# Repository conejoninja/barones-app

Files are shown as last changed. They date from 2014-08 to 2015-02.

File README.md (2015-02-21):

Breathalyzer on your smartphone
===

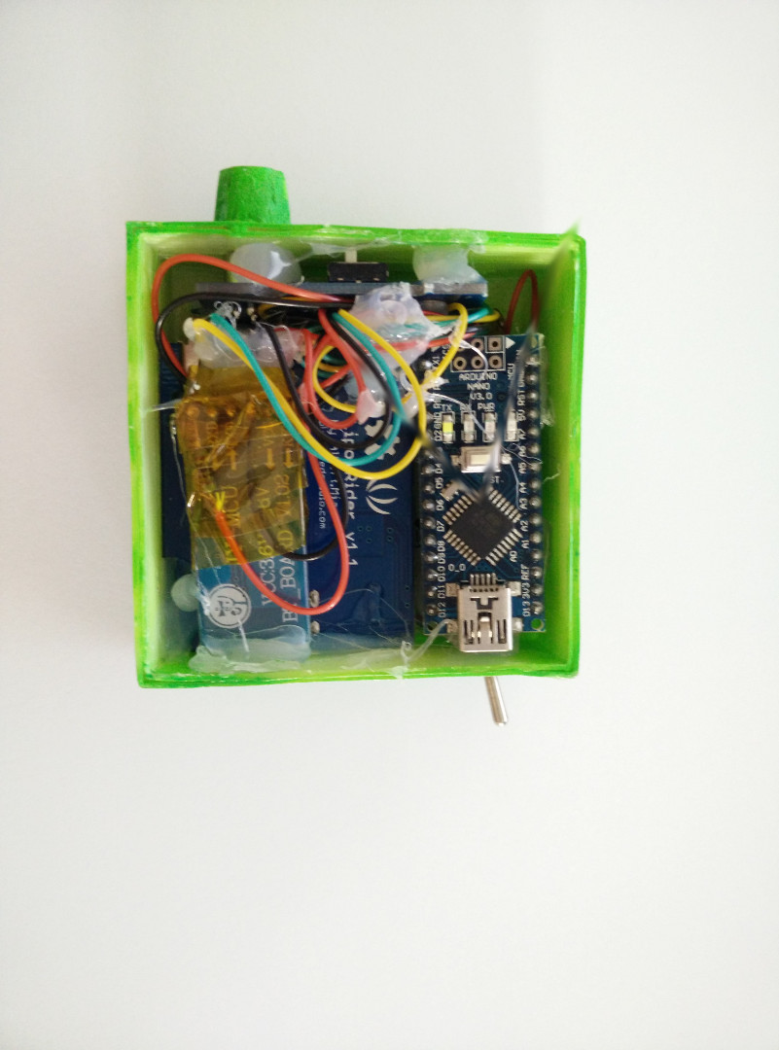
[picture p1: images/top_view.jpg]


Connect a breathalyzer to your smartphone and take pictures of your drunk friends with their highscores.
This project was around two years in the making, I started doing it in Java (the Android part) but got frustrated and left the project sitting in a box all this time. For the smartphone app I'm using phonegap/cordova, so it should work on iOS or windows phone, or at least, it should be easy to be ported. 

The idea isn't new, but all similar projects I found, didn't share the smartphone app's code, I do. It isn't the nicest app you could find, but it works.

I tried to recover all the information I wrote done when I first build this, I got most important information but some details and pictures are missing.

Bill of materials
===
* 1 Arduino nano 9-10€ , there a lot of different models and places to buy it
* 1 Grove-Alcohol sensor (seeedstudio) 5.90€ (7.90$) - http://www.seeedstudio.com/depot/Grove-Alcohol-Sensor-p-764.html
* 1 Li-po rider (seeedstudio) 7.08€ (9.50$) - http://www.seeedstudio.com/depot/Lipo-Rider-p-710.html
* 1 DSO Nano v2 replacement battery (seeedstudio) 4.10€ (5.50$) - http://www.seeedstudio.com/depot/DSO-Nano-v2-replacement-battery-p-738.html
* 1 Bluetooth module 4.80€ (6.43$) - http://www.dx.com/p/jy-mcu-arduino-bluetooth-wireless-serial-port-module-104299 (I think I bought it from ebay, and bought a pair, but is similar to this if not the same) 
* 1 Shipping from seeedstudio 2.56€ (3.44$)
* 1 3D printed case and paint 5€ (no idea, as I printed it mayself, but a small plastic case shouldn't cost much more)
* 1 switch, 2 leds, glue,.. less than 2-3€

**Aproximate cost: 40-45€**

Alcohol sensor
===

Schematics and code was taken from here : http://www.seeedstudio.com/wiki/index.php?title=Twig_-_Alcohol_Sensor
It uses the MQ303A.

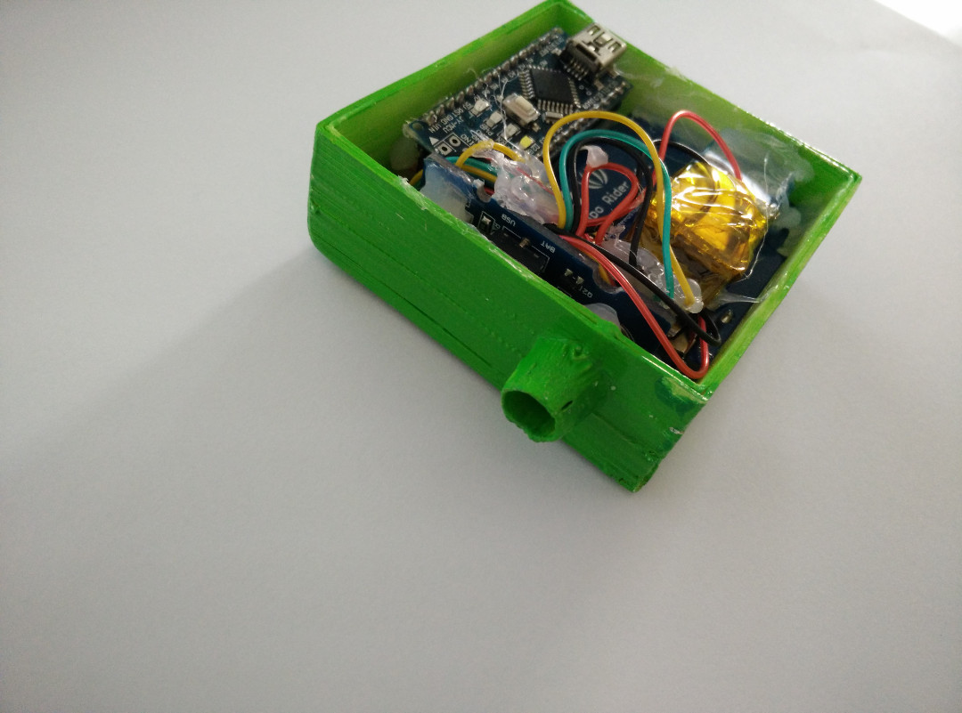
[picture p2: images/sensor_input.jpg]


Features
---

* Input Voltage: 5V
* Working Current: 120mA
* Detectable Concentration: 20-1000ppm
* Grove Compatible connector
* Highly sensitive to alcohol.
* Fast response and resumes quickly after alcohol exposure.
* Long life.
* Compact form factor.

Notes
---
To get better measurement, sensor needs to be power on for several hours before usage. Since this is a "for-fun" app, there's no need to wait long time, and after a few minutes (20-30min) readings are more or less stable. It could last several hours with one full charge of battery. 

Bluetooth module
===
I use the *JY-MCU* module, very famous and cheap. You can find it in several stores (eBay, AliExpress, DX,...). I also connect one led to their *state* output. This led will pulse when not connected and switch to permanent on when connected.
 
**You need to program the BT module first**
You could use the .ino code in *arduino/ProgramBTModule* to program your BT module. Connect RX (arduino digital pin 2) to TX (BT), and TX (arduino digital pin 3) to RX (BT), upload the code to the arduino and wait a few seconds. The device should appear as *CONEJO-ALCOHOL* in your phone's BT devices list.

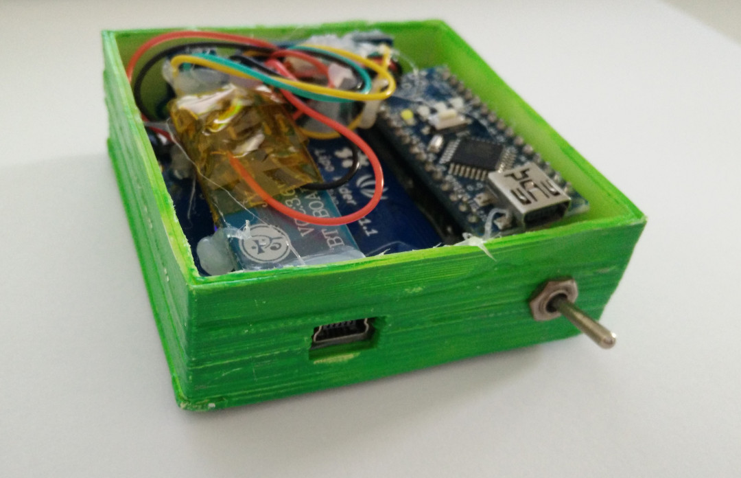
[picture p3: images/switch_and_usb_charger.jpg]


Schematic
===
Handmade schematic since I didn't have the parts in Fritzing or any other schematic editor, I know it's a mess and ugly.

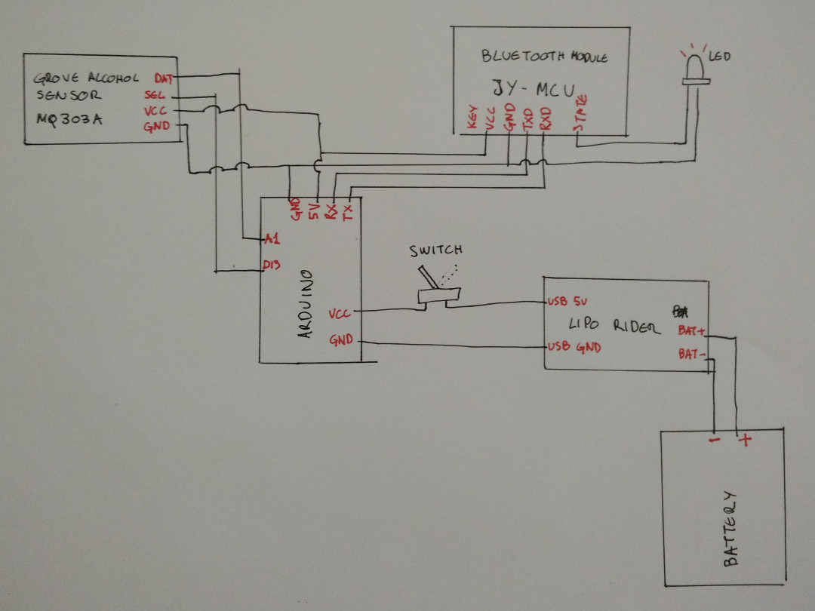
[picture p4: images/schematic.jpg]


The box
===
Folder openscad-box contains the OpensSCAD and STL files for 3D printing it. Any small box could work too.

Mobile App
===
The mobile app is done with Phonegap/Cordova ( + angularJS), you need it in your system and this small README file will not cover its installation or general usage. To generate (in my case) the android code, just run *'phonegap build android'*, later, create the APK with your favorite method (I use Intellij IDEA). The app is really simple, it doesn't catch many errors, but **it works**. Needs work on the texts and on the style of menus, but I'm really bad at it.

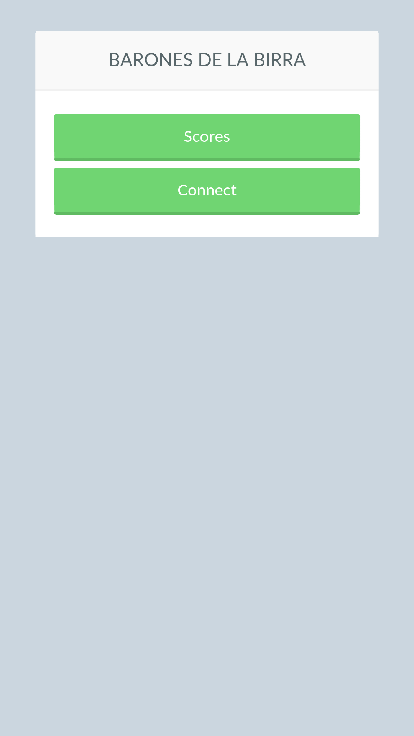
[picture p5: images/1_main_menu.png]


*Home menu, once you're connected, a new option 'Test' will appear*

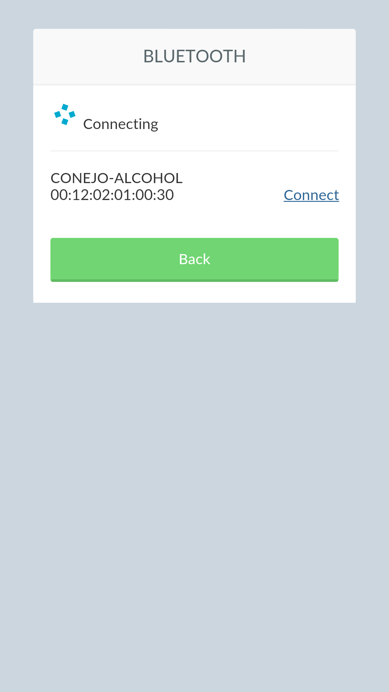
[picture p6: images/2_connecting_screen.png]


*Connecting to your BT device (alcohol sensor)*

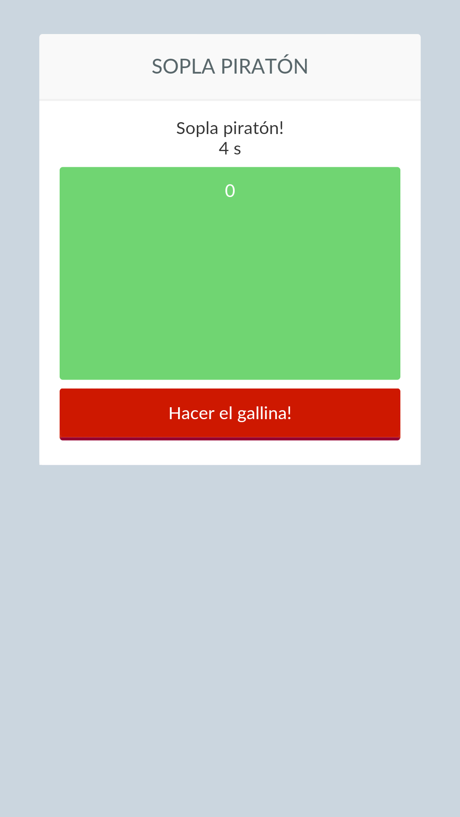
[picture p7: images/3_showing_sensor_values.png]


*Blow into the sensor during 10 seconds*

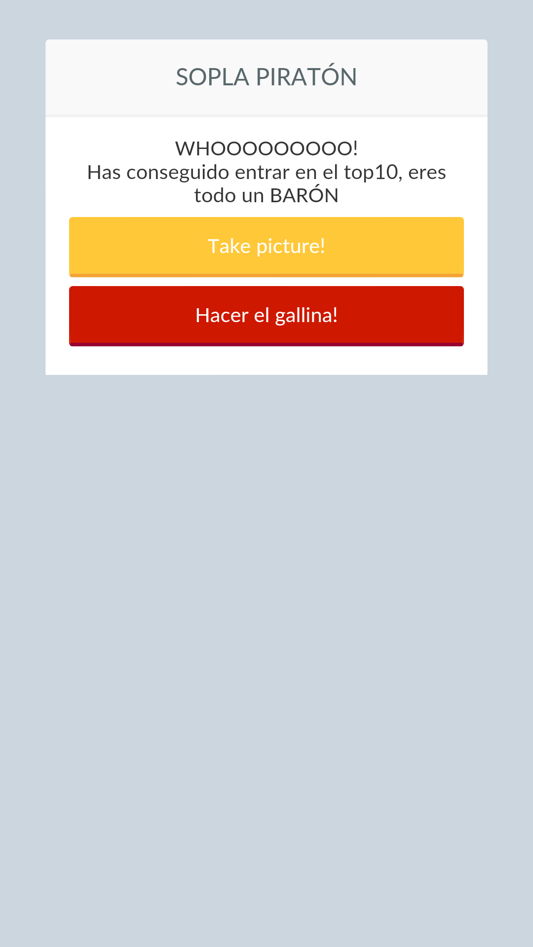
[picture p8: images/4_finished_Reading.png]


*If your 'score' is higher than the lower one, you enter the hall of fame (or shame, I'm not sure)*

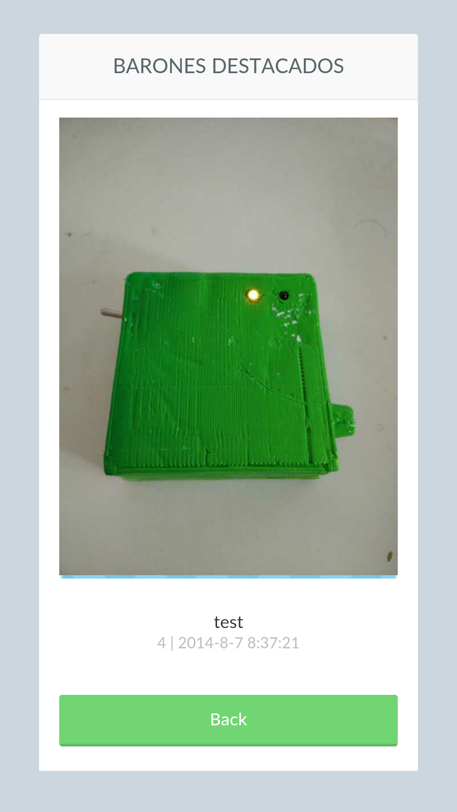
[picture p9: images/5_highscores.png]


*Hall of fame (shame), picture, name, score and date*

Disclaimer
===
This project was developed for fun, do not expect accurate results. For a more serious readings you will probably need better components. Blood Alcohol Content (BAC) could only be estimated from a breath sample and it's usually highly inaccurate. **If you need a breathanalyzer to know if you're able to drive, you should not drive. Drink responsibly.**

Licenses
===
This is distributed under the Apache License v2.0 unless some library or code isn't compatible ):

Copyright 2014 Daniel Esteban  -  conejo@conejo.me

Licensed under the Apache License, Version 2.0 (the "License");
you may not use this file except in compliance with the License.
You may obtain a copy of the License at

    http://www.apache.org/licenses/LICENSE-2.0

Unless required by applicable law or agreed to in writing, software
distributed under the License is distributed on an "AS IS" BASIS,
WITHOUT WARRANTIES OR CONDITIONS OF ANY KIND, either express or implied.
See the License for the specific language governing permissions and
limitations under the License.

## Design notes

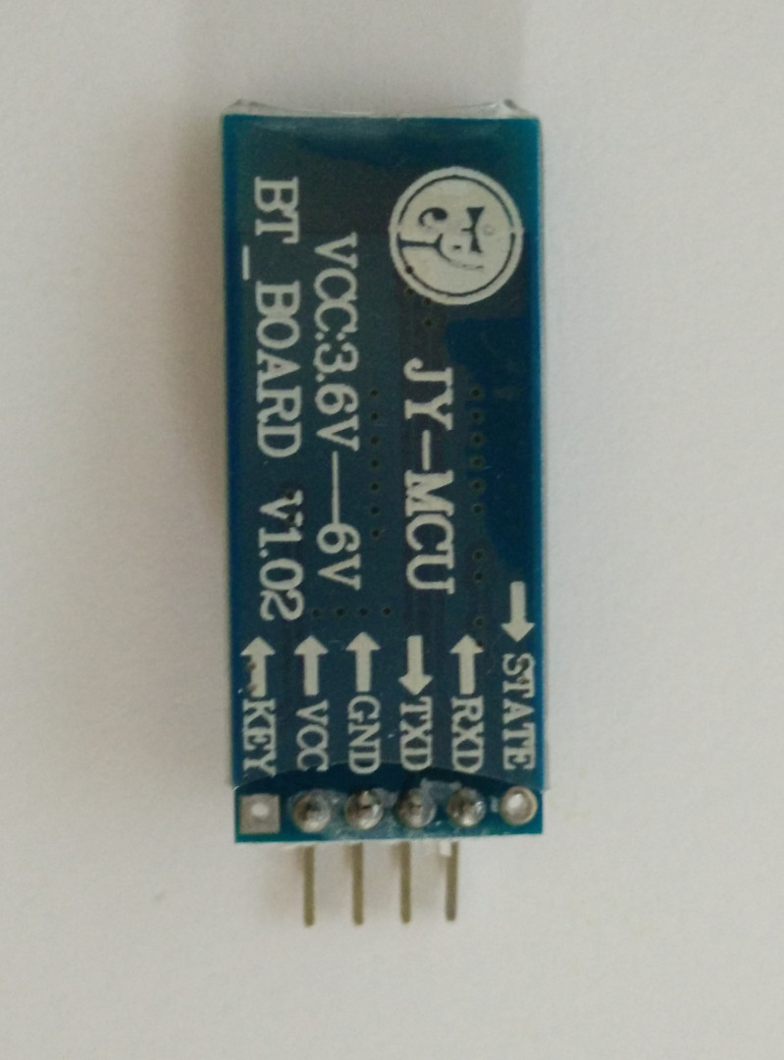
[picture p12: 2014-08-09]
images/bt_module_used.jpg

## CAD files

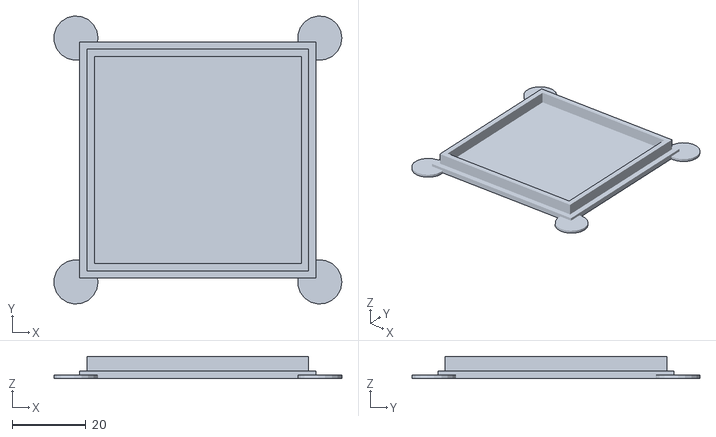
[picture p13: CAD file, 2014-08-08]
openscad-box/baralcohol-top.stl
77.9 x 78.0 x 6.00

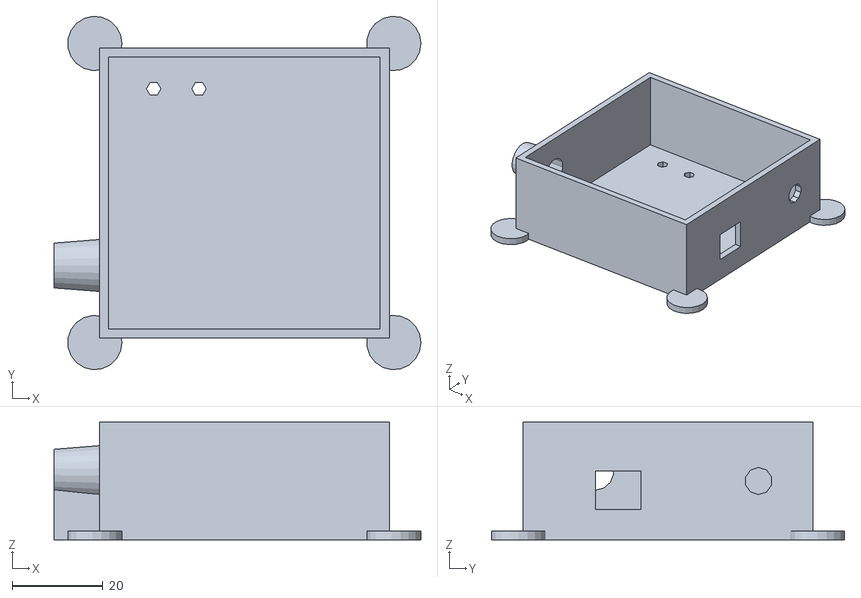
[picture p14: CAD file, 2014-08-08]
openscad-box/baralcohol.stl
81.0 x 78.0 x 26.0

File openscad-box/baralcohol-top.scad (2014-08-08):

cube([64,64,2], true);
difference(){
	translate([0,0,3]) {
		cube([60,60,4], true);
	}
	translate([0,0,3]) {
		cube([56,56,5], true);
	}
}

withmouseears();

// MOUSE EARS TO HELP AVOID WARPING
module withmouseears() {
	mouseear(33,33,-1);
	mouseear(33,-33,-1);
	mouseear(-33,-33,-1);
	mouseear(-33,33,-1);
}



module mouseear(x,y,z) {
	translate([x,y,z]) {
		cylinder(1,6,6);
	}
}

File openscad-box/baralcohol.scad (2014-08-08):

difference(){
	difference(){
		difference(){
			difference(){
				// MAIN BOX
					difference() {
						union(){
							cube([64,64,26], true);
							// MOUNTH TUBE
							translate([-42,-16,2]){
								rotate([00,90,0]) {
									cylinder(25,5,7);
								}
							}
						}
						translate([0,0,2]){cube([60,60,24], true);}
					}
				// MQ303A
				translate([-48,-16,2]){
					rotate([0,90,0]) {
						cylinder(30,4,4);
					}
				}
			}
			//POWER SWITCH
			translate([25,20,0]){
				rotate([0,90,0]) {
					cylinder(10,3,3);
				}
				}
		}
		//MINI USB BATTERY CHARGER
		translate([28,-11,-2]){
			cube([11,10,8.5],true);
		}
	}
	// LEDS
	union() {
		// POWER LED
		translate([-20,23,-15]) {
			cylinder(10,1.6,1.6);
		}			
		// BLUETOOTH LED
		translate([-10,23,-15]) {
			cylinder(10,1.6,1.6);
		}			
	}
}

//ADDITIONAL FEATURES TO HELP PRINTING AND AVOID WARPING
withsupport();
withmouseears();




// SUPPORTS FOR PRINTING
module withsupport() {
	translate([-42,-14,-13]) {
		cube([10,1,11]);
	}
	translate([-42,-19,-13]) {
		cube([10,1,11]);
	}
}



// MOUSE EARS TO HELP AVOID WARPING
module withmouseears() {
	mouseear(33,33,-13);
	mouseear(33,-33,-13);
	mouseear(-33,-33,-13);
	mouseear(-33,33,-13);
}



module mouseear(x,y,z) {
	translate([x,y,z]) {
		cylinder(2,6,6);
	}
}

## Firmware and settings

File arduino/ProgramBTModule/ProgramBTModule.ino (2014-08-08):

/*
  Software serial multple serial test
 
 Receives from the hardware serial, sends to software serial.
 Receives from software serial, sends to hardware serial.
 
 The circuit: 
 * RX is digital pin 2 (connect to TX of other device)
 * TX is digital pin 3 (connect to RX of other device)
 
 created back in the mists of time
 by Tom Igoe
 based on Mikal Hart's example
 
 This example code is in the public domain.
 
 */
#include <SoftwareSerial.h>

SoftwareSerial mySerial(2, 3); // RX, TX

void setup()  
{
  Serial.begin(57600);
  Serial.println("Goodnight moon!");

  // set the data rate for the SoftwareSerial port
  mySerial.begin(9600);
  delay(1000);
  mySerial.print("AT");
  delay(1000);
  mySerial.print("AT+VERSION");
  delay(1000);
  mySerial.print("AT+PIN1111");
  delay(1000);
  mySerial.print("AT+NAMECONEJO-ALCOHOL");
  delay(1000);
  mySerial.print("AT");
}

void loop() // run over and over
{
  if (mySerial.available())
    Serial.write(mySerial.read());
  if (Serial.available())
    mySerial.write(Serial.read());
}

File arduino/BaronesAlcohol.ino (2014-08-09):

//MQ303A Testing - A simple sketch to understand the working of Alcohol sensor. Can be used to study how to calibrate threshold values.   
 
//Alcohol Sensor DAT Pin is connected to Analog Input Pin a (A1)
#define analogInDatPin A1
 
//Alcohol Sensor SEL Pin is connected to Digital Pin 13 (13).
#define heaterSelPin 13
 
int sensorValue = 0;        
 
void setup() {
  pinMode(heaterSelPin,OUTPUT);    // set the heaterSelPin as digital output.
  digitalWrite(heaterSelPin,HIGH); //when heaterSelPin is set, heater is switched off.
  Serial.begin(9600);  // open the serial port at 9600 bps
}
void loop() {
  digitalWrite(heaterSelPin,LOW);             //switch on the heater of Alcohol sensor
  sensorValue = analogRead(analogInDatPin);   //read the analog value 
 
  //Disply the results in serial monitor.
  //sensorValue goes down when alcohol is detected. Hence subtracting from 1023.
  Serial.println(1023-sensorValue); 
  delay(100);  
}

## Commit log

2014-08-08 first blood
    [baralcohol-top.scad, baralcohol-top.stl, baralcohol.scad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]
2014-08-09 re-added arduino files
